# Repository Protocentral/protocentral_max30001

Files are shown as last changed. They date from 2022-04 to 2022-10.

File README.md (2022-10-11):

# ProtoCentral MAX30001 ECG and Respiration/Bio-Impedance Breakout Board

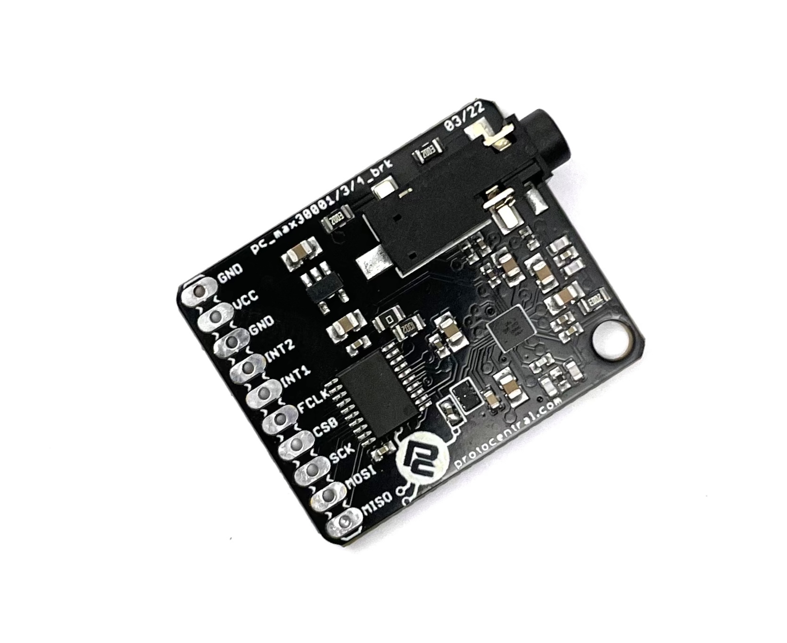
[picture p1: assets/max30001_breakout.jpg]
ProtoCentral MAX30001 ECG and Respiration/Bio-Impedance Breakout Board


If you dont already have one, you can buy [ProtoCentral MAX30001 ECG and Respiration/Bio-Impedance Breakout Board here.](https://protocentral.com/product/protocentral-max30001/)

MAX30001 is a single-lead ECG monitoring IC which has built-in R-R detection and several other features that make it perfect for a wearable single-lead ECG application.  

Several new features on this chip make it ideal for wearable applications. First is the low power consumption - just 85 uW of power and can work from 1.1 V onwards ! Also of interest is the fact that it can work with only two chest electrodes without the need for a third right-leg drive (DRL) electrode.

The best feature of this chip though is the built-in R-R detection algorithm which can measure the time between successive peaks of the QRS complex of the ECG. This means that heart-computation comes right out of the box without any microcontroller-side code requirement. Heart-rate computation just got a lot easier !!

# Features

* MAX30001 single channel integrated front-end (AFE) chip
* Single-lead ECG monitoring ( three electrodes, optional right leg drive)
* Capable of measuring respiration
* Clinical-Grade ECG and BioZ AFE with High Resolution
* Inbuilt R-R detection and Pace detection
* Flexibility for 2 or 3 electrode measurements
* ADC Resolution is 18 bits 
* High DC Offset range of ±650mV(excellent tolerance to motion artifacts)
* Onboard 3.3V voltage regulator for low noise.
* Onboard logic level translators for Arduino interface.

# What's included

* ProtoCentral MAX30001 ECG and Respiration/Bio-Impedance Breakout Board
* Straight pin headers
* 2-electrode ECG connector with stereo connector
* 10x disposable ECG stick-on electrodes

# Repository Contents

* **/software** - Arduino library and example sketches.
* **/hardware** - All Eagle hardware design files

# Wiring the board to your Arduino

If you have bought the breakout the connection with the Arduino board is as follows:

|MAX30001 pin label| Arduino Connection |Pin Function |
|--- |:---:|---:|
| MISO | D12 |  Slave out| 
| MOSI | D11 |  Slave in |
| SCK | D13 |  Serial clock |
| CS0 | D7 |  Slave select|
| FCLK | NC |  External clock(32KHz) |
| INT1 | D2 |  Interrupt |
| INT2 | NC |  Interrupt |
| 3V3 | Supply |  Board which supports 3.3V and 1.8V |
| VCC | Supply 5V | 5V |
| GND | Gnd  

# Running the Arduino Sketch

If you have correctly installed the libraries, the example sketeches should now be available from within Arduino.

[Download the Arduino Sketch here for this board here.](https://github.com/Protocentral/protocentral_max30001/releases/download/v0.1/protocentral_max30001_arduino.zip)

Open up your Arduino IDE and run the Arudino sketch (.ino) file in the archive that you downloaded. Your Arduino should now be programmed to read the ecg data and sending over the USB-UART.  

# Using the ProtoCentral OpenView GUI

The GUI for visualizing the ECG and Respiration as well as parameters like Heart rate and Respiration rate is written in Processing, based on Java and is cross-compilable across platforms.

Java 8 is required on all platforms for running the processing-based GUI application. You can download Java for your platform from the [Official Java website](https://www.java.com/en/download/).

You can download and install [ProtoCentral OpenView from here](https://github.com/Protocentral/protocentral_openview).

Once you have opened OpenView, make sure to select "MAX30001 breakout" under the "Board" dropdown. 

# Connecting the ECG Electrodes

A 2-electrode cable along with a standard stereo jack is provided along with the shield to connect the electrodes to the board. The electrode input connector is highlighted in the below picture.

The other side of the electrode connector would connect to snap-on electrodes attached to the body. For testing purposes, you can use an ECG simulator to provide inputs to the board.

*Warning:
When connecting the electodes to the body, it is safer to disconnect the mains power source to the Arduino. For example, if  you are using the Arduino along with a laptop, disconnecting the battery charger from the laptop would be a safe option.*

# Placing the Electrodes on the body

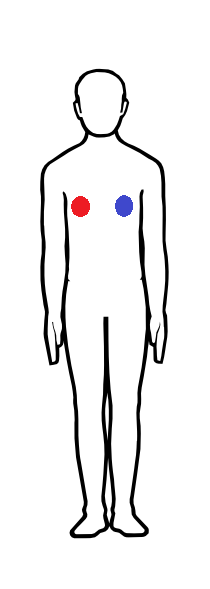
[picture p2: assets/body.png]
Wearing the Electrode


License Information
===================

License

This product is open source! Both, our hardware and software are open source and licensed under the following licenses:

Hardware
---------

**All hardware is released under the [CERN-OHL-P v2](https://ohwr.org/cern_ohl_p_v2.txt)** license.

Copyright CERN 2020.

This source describes Open Hardware and is licensed under the CERN-OHL-P v2.

You may redistribute and modify this documentation and make products
using it under the terms of the CERN-OHL-P v2 (https:/cern.ch/cern-ohl).
This documentation is distributed WITHOUT ANY EXPRESS OR IMPLIED
WARRANTY, INCLUDING OF MERCHANTABILITY, SATISFACTORY QUALITY
AND FITNESS FOR A PARTICULAR PURPOSE. Please see the CERN-OHL-P v2
for applicable conditions

Software
--------

**All software is released under the MIT License(http://opensource.org/licenses/MIT).**

THE SOFTWARE IS PROVIDED "AS IS", WITHOUT WARRANTY OF ANY KIND, EXPRESS OR IMPLIED, INCLUDING BUT NOT LIMITED TO THE WARRANTIES OF MERCHANTABILITY, FITNESS FOR A PARTICULAR PURPOSE AND NONINFRINGEMENT. IN NO EVENT SHALL THE AUTHORS OR COPYRIGHT HOLDERS BE LIABLE FOR ANY CLAIM, DAMAGES OR OTHER LIABILITY, WHETHER IN AN ACTION OF CONTRACT, TORT OR OTHERWISE, ARISING FROM, OUT OF OR IN CONNECTION WITH THE SOFTWARE OR THE USE OR OTHER DEALINGS IN THE SOFTWARE.

Documentation
-------------
**All documentation is released under [Creative Commons Share-alike 4.0 International](http://creativecommons.org/licenses/by-sa/4.0/).**


You are free to:

* Share — copy and redistribute the material in any medium or format
* Adapt — remix, transform, and build upon the material for any purpose, even commercially.
The licensor cannot revoke these freedoms as long as you follow the license terms.

Under the following terms:

* Attribution — You must give appropriate credit, provide a link to the license, and indicate if changes were made. You may do so in any reasonable manner, but not in any way that suggests the licensor endorses you or your use.
* ShareAlike — If you remix, transform, or build upon the material, you must distribute your contributions under the same license as the original.

Please check [*LICENSE.md*](LICENSE.md) for detailed license descriptions.

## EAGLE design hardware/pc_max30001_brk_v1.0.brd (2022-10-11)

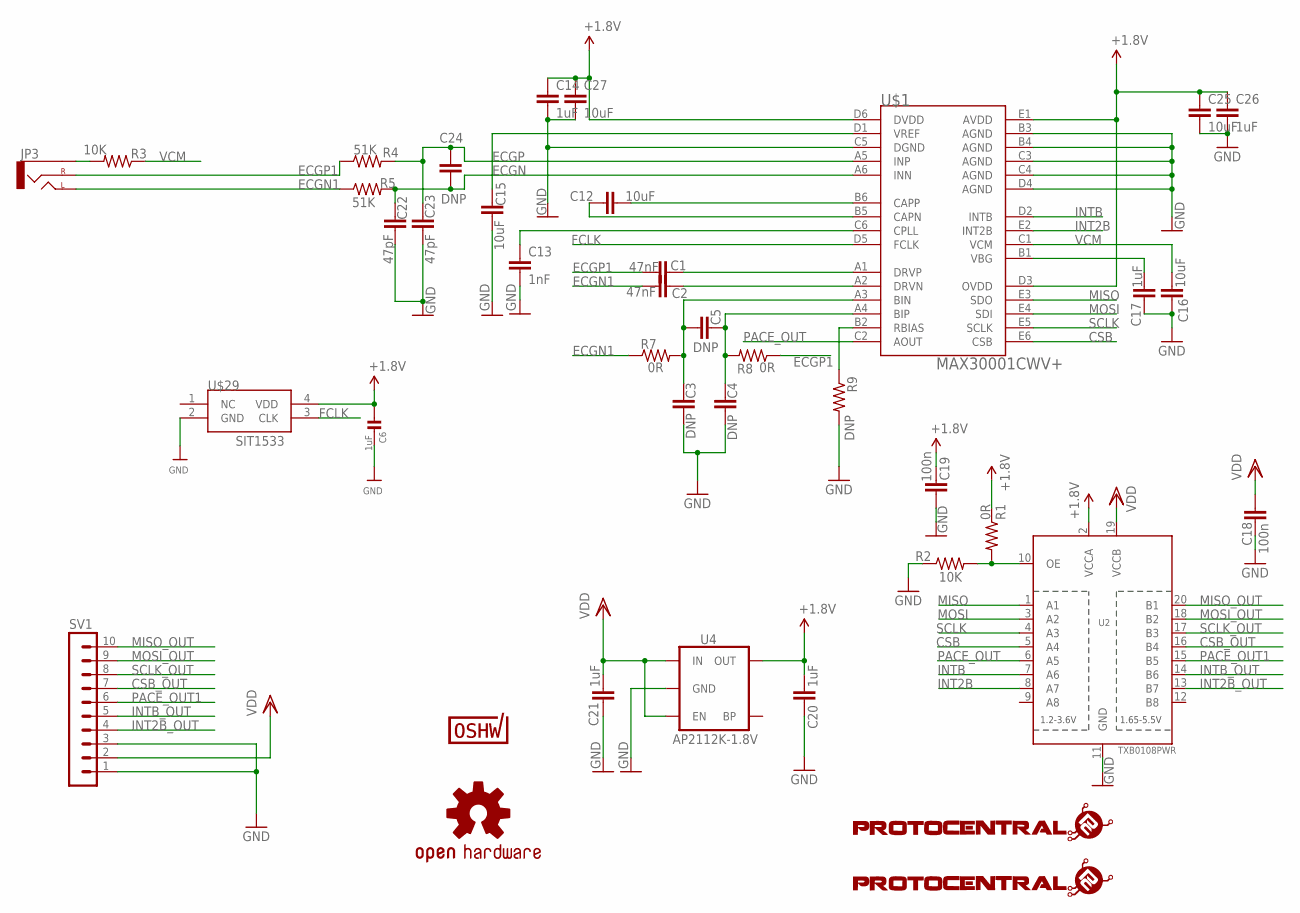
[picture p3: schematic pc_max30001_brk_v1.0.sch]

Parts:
C1, C2: 47nF; C0402
C3, C4, C5, C24: DNP; C0402
C6: 1uF; 0402
C12, C15, C16, C25, C27: 10uF; C0805
C13: 1nF; C0402
C14, C17, C26: 1uF; C0402
C18, C19: 100n; C0402
C20, C21: 1uF; C0805
C22, C23: 47pF; C0402
JP3: AUDIO-JACKSMD2; AUDIO-JACK-3.5MM-SMD
R1: 0R; 0805
R2, R3: 10K; 0805
R4, R5: 51K; 0805
R7, R8: 0R; 0402-RES
R9: DNP; 0402-RES
SV1: MA10-1
U2: TXB0108PWR; TSSOP20
U4: AP2112K-1.8V; SOT23-5
U$1: MAX30001CWV+; 30WLP
U$3: PROTY-LOGO; LOGO-PROTY
U$4: PROTY_LOGO_WITH_TEXT; PROTY_WITH_TEXT
U$6: OSHW-LOGOS; OSHW-LOGO-S
U$7: CERT-SMALL; CERT-SMALL-SILK
U$29: SIT1533

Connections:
+1.8V: C6.1, C14.1, C19.2, C20.2, C25.1, C26.1, C27.1, R1.1, U2.2 (VCCA), U4.5 (OUT), U$1.D3 (OVDD), U$1.D6 (DVDD), U$1.E1 (AVDD), U$29.4 (VDD)
CSB: U2.5 (A4), U$1.E6 (CSB)
CSB_OUT: SV1.7, U2.16 (B4)
ECGN: C22.1, C24.2, R5.2, U$1.A6 (INN)
ECGN1: C2.1, JP3.TIP (LEFT), R5.1, R7.1
ECGP: C23.1, C24.1, R4.2, U$1.A5 (INP)
ECGP1: C1.1, JP3.RING (RIGHT), R4.1, R8.1
FCLK: U$1.D5 (FCLK), U$29.3 (CLK)
GND: C3.2, C4.2, C6.2, C13.2, C14.2, C15.2, C16.2, C17.2, C18.1, C19.1, C20.1, C21.1, C22.2, C23.2, C25.2, C26.2, C27.2, R2.1, R9.2, SV1.1, SV1.3, U2.11 (GND), U4.2 (GND), U$1.B3 (AGND), U$1.B4 (AGND), U$1.C3 (AGND), U$1.C4 (AGND), U$1.C5 (DGND), U$1.D4 (AGND), U$29.2 (GND)
INT2B: U2.8 (A7), U$1.E2 (INT2B)
INT2B_OUT: SV1.4, U2.13 (B7)
INTB: U2.7 (A6), U$1.D2 (INTB)
INTB_OUT: SV1.5, U2.14 (B6)
MISO: U2.1 (A1), U$1.E3 (SDO)
MISO_OUT: SV1.10, U2.20 (B1)
MOSI: U2.3 (A2), U$1.E4 (SDI)
MOSI_OUT: SV1.9, U2.18 (B2)
unnamed: C12.1, U$1.B6 (CAPP)
unnamed: C1.2, U$1.A1 (DRVP)
unnamed: C2.2, U$1.A2 (DRVN)
unnamed: C3.1, C5.1, R7.2, U$1.A3 (BIN)
unnamed: C4.1, C5.2, R8.2, U$1.A4 (BIP)
unnamed: R9.1, U$1.B2 (RBIAS)
unnamed: C13.1, U$1.C6 (CPLL)
unnamed: C12.2, U$1.B5 (CAPN)
unnamed: C15.1, U$1.D1 (VREF)
unnamed: C17.1, U$1.B1 (VBG)
unnamed: R1.2, R2.2, U2.10 (OE)
unnamed: JP3.SLEEVE, R3.2
PACE_OUT: U2.6 (A5), U$1.C2 (AOUT)
PACE_OUT1: SV1.6, U2.15 (B5)
SCLK: U2.4 (A3), U$1.E5 (SCLK)
SCLK_OUT: SV1.8, U2.17 (B3)
VCM: C16.1, R3.1, U$1.C1 (VCM)
VDD: C18.2, C21.2, SV1.2, U2.19 (VCCB), U4.1 (IN), U4.3 (EN)

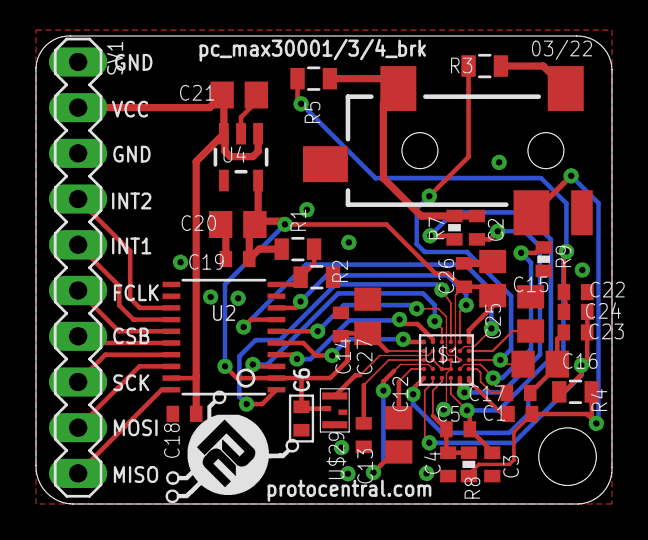
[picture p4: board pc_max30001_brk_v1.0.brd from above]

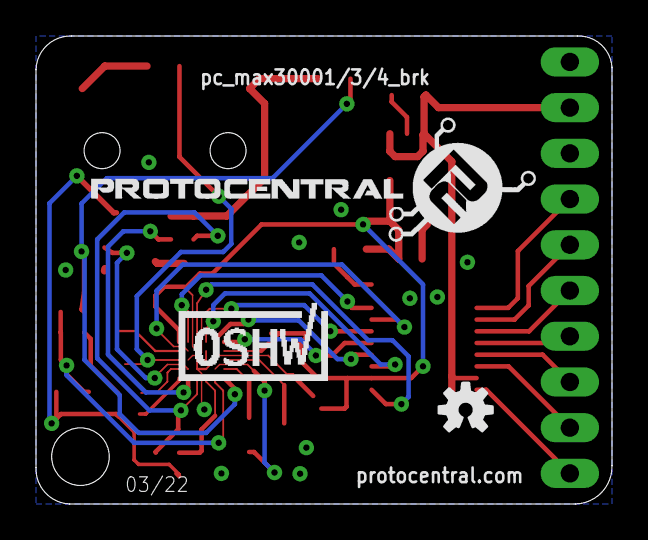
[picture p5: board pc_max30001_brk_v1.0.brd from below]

Board: 4 copper layers, 32.0 x 26.0 mm, 40 parts (3 on the bottom side), 35 nets.

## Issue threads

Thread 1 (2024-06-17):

nconsistent Raw BioZ Values from Identical MAX30001 Sensors

jali6065, 2024-06-17:
Software:

[protocentral_max30001](version: 1.2)

Steps to Reproduce:

Connect both MAX30001 sensors to the same Arduino board.
Configure both sensors with identical settings (e.g., sample rate, gain, lead-off detection).
Place electrodes in the same locations on two different subjects (or the same subject for multiple readings).
Read raw BioZ values from both sensors simultaneously.
Observe the difference in the values.

Expected Behavior:

I expect the raw BioZ values from both sensors to be relatively close to each other, given the identical setup and conditions.

Actual Behavior:

The raw BioZ values from the two sensors show a significant difference, even when measured under the same conditions. The values can sometimes differ by orders of magnitude.
BioZ raw: 524191, BioZ raw: 70.
two values of sensors.

Oliver0804, 2024-07-31:
Bioz raw's data is a bit different...
Is it possible to swap two modules for testing?
I think there's something wrong with the programme.

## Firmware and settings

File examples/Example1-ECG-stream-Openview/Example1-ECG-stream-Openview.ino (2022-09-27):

//////////////////////////////////////////////////////////////////////////////////////////
//
//    Demo code for the MAX30001 breakout board
//
//    This example plots the ECG through serial UART on openview processing GUI.
//    GUI URL: https://github.com/Protocentral/protocentral_openview.git
//
//    Arduino connections:
//
//  |MAX30001 pin label| Pin Function         |Arduino Connection|
//  |----------------- |:--------------------:|-----------------:|
//  | MISO             | Slave Out            |  D12             |
//  | MOSI             | Slave In             |  D11             |
//  | SCLK             | Serial Clock         |  D13             |
//  | CS               | Chip Select          |  D7              |
//  | VCC              | Digital VDD          |  +5V             |
//  | GND              | Digital Gnd          |  Gnd             |
//  | FCLK             | 32K CLOCK            |  -               |
//  | INT1             | Interrupt1           |  02              |
//  | INT2             | Interrupt2           |  -               |
//
//    This software is licensed under the MIT License(http://opensource.org/licenses/MIT).
//
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
//   For information on how to use, visit https://github.com/Protocentral/protocentral_max30001
//
/////////////////////////////////////////////////////////////////////////////////////////

#include <SPI.h>
#include "protocentral_max30001.h"

#define MAX30001_CS_PIN         7
#define MAX30001_DELAY_SAMPLES  8 // Time between consecutive samples

#define PC_OV_CMDIF_PKT_START_1 0x0A
#define PC_OV_CMDIF_PKT_START_2 0xFA
#define PC_OV_CMDIF_TYPE_DATA 0x02
#define PC_OV_CMDIF_PKT_STOP 0x0B

#define DATA_LEN 0x0C
#define ZERO 0

volatile char DataPacket[DATA_LEN];
const char DataPacketFooter[2] = {ZERO, PC_OV_CMDIF_PKT_STOP};
const char DataPacketHeader[5] = {PC_OV_CMDIF_PKT_START_1, PC_OV_CMDIF_PKT_START_2, DATA_LEN, ZERO, PC_OV_CMDIF_TYPE_DATA};

uint8_t data_len = 0x0C;

MAX30001 max30001(MAX30001_CS_PIN);

signed long ecg_data;
signed long bioz_data;

void sendData(signed long ecg_sample, signed long bioz_sample)
{

  DataPacket[0] = ecg_sample;
  DataPacket[1] = ecg_sample >> 8;
  DataPacket[2] = ecg_sample >> 16;
  DataPacket[3] = ecg_sample >> 24;

  DataPacket[4] = bioz_sample;
  DataPacket[5] = bioz_sample >> 8;
  DataPacket[6] = bioz_sample >> 16;
  DataPacket[7] = bioz_sample >> 24;

  DataPacket[8] = 0x00; // max30001.heartRate;
  DataPacket[9] = 0x00; // max30001.heartRate >> 8;
  DataPacket[10] = 0x00;
  DataPacket[11] = 0x00;
  
  // Send packet header (in ProtoCentral OpenView format)
  for (int i = 0; i < 5; i++)
  {
    Serial.write(DataPacketHeader[i]);
  }

  // Send the data payload
  for (int i = 0; i < DATA_LEN; i++) // transmit the data
  {
    Serial.write(DataPacket[i]);
  }

  // Send packet footer (in ProtoCentral OpenView format)
  for (int i = 0; i < 2; i++)
  {
    Serial.write(DataPacketFooter[i]);
  }
}

void setup()
{
  Serial.begin(57600);

  SPI.begin();
  SPI.setBitOrder(MSBFIRST);
  SPI.setDataMode(SPI_MODE0);

  bool ret = max30001.max30001ReadInfo();
  if (ret)
  {
    Serial.println("MAX 30001 read ID Success");
  }
  else
  {
    while (!ret)
    {
      // Keep trying every 5 seconds
      ret = max30001.max30001ReadInfo();
      Serial.println("Failed to read ID, please make sure all the pins are connected");
      delay(5000);
    }
  }

  max30001.BeginECGBioZ(); // Start sampling in ECG and BioZ modes                     
}

void loop()
{
  ecg_data = max30001.getECGSamples();
  // max30001.getHRandRR();
  bioz_data = max30001.getBioZSamples();
  sendData(ecg_data, bioz_data);

  delay(8*2);
}

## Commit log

2022-09-26 Corrected packet format in example
    [Example1-ECG-stream-Openview.ino]
2022-10-08 Removed Arduino Library files

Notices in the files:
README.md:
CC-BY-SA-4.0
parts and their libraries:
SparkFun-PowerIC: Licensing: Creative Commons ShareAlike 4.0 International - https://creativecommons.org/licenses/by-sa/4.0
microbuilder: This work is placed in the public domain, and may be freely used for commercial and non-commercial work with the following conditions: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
